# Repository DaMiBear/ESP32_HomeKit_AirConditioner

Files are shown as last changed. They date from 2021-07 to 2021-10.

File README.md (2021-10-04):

# 接入HomeKit的ESP32空调控制器
## 更新日志

- **2021.9.25**：根据power_save例程添加了light-sleep模式及DFS，系统自动决定CPU频率和是否进入light-sleep模式。

  **因为手里只有一个量程为20A的电流表（小量程用不了），测得结果肯定不准确，之前的代码在不用家庭App操控时的电流大约为30\~40mA，现在大约为10\~20mA，如果与家庭App通信时电流大约为40~70mA**

  目前只添加了WiFi使用HARDCODED时的代码；以及`rmt_config_t`变量中的成员`flags`设置为`RMT_CHANNEL_FLAGS_AWARE_DFS`和`clk_div`为`1`以支持DFS；在发生红外指令时，调用电源管理锁`esp_pm_lock_handle_t`防止自动进入light-sleep模式。

  1. 需要在menuconfig中启动`Support for power management`和`Tickless idle support`选项，以及进行`WiFi listen interval`、`power save mode`和`Maximum/Minimum CPU frequency`配置

  2. 需要在`esp-homekit-sdk/examples/common/app_wifi/app_wifi.c`中275行
  
  ```c
  #ifdef CONFIG_APP_WIFI_USE_HARDCODED
  #define APP_WIFI_SSID   CONFIG_APP_WIFI_SSID
  #define APP_WIFI_PASS   CONFIG_APP_WIFI_PASSWORD
  ```

  下面添加如下宏定义：
  
  ```c
  #define DEFAULT_LISTEN_INTERVAL CONFIG_APP_WIFI_LISTEN_INTERVAL
  
  #if CONFIG_APP_POWER_SAVE_MIN_MODEM
  #define DEFAULT_PS_MODE WIFI_PS_MIN_MODEM
  #elif CONFIG_APP_POWER_SAVE_MAX_MODEM
  #define DEFAULT_PS_MODE WIFI_PS_MAX_MODEM
  #elif CONFIG_APP_POWER_SAVE_NONE
  #define DEFAULT_PS_MODE WIFI_PS_NONE
  #else
  #define DEFAULT_PS_MODE WIFI_PS_NONE
  #endif /*CONFIG_POWER_SAVE_MODEM*/
  ```

  3. `app_wifi_start()`函数中`password`下面添加一行

  `.listen_interval = DEFAULT_LISTEN_INTERVAL,`

  4. `ESP_ERROR_CHECK(esp_wifi_start() );`下面添加
  
  ```c
  ESP_LOGI(TAG, "esp_wifi_set_ps().");
  esp_wifi_set_ps(DEFAULT_PS_MODE);
  ```
  
  > 相关宏定义会在main/Kconfig.projbuild文件中自动生成。
  >
  > 附上修改后的[app_wifi.c](/docs/changed_src/app_wifi.c)文件。

## 介绍

- 因为宿舍空调遥控器有问题，而且最近没啥事情做，所以想到使用ESP32做一个空调伴侣，接入Apple的HomeKit实现iOS设备对空调的控制，目前只能对美的空调进行控制，只包括基本功能：**开关**、**模式**(自动、制冷、制热)、**温度**(制冷17-30℃，制热17-25℃)、**风速**(自动风、低、中、高风)。锂电池供电，可用MicroUSB接口充电，充满自动断开，基本的锂电池保护（硬件是设计了但我也没实际测试过O(∩_∩)O），锂电池保护，DW07D这里要注意一点，就是如果第一次装上电池，需要先充电一下才能正常供电，只要不把电池拆下来，就不必再这样做。

- 目前问题或bug(具体原因[笔记](/Note.md)中会解释)：
	- 家庭App界面，在设定空调一些参数后（比如模式），长按配件后出现的设定界面会更新状态，但是打开家庭的初始界面中不能立刻更新，必须把家庭App切到后台再切回来才能更新。
	- 家庭App中空调制热的设定范围，注意是显示的设定范围，是到0\~25℃，制冷温度的设定范围是10\~35℃，实际上如果超出了17\~30℃这个范围的话就还是17℃或者30℃。

- 这个项目参考了乐鑫的homekitSDK和ESP-IDF中的红外NEC编码示例。以及美的的R05D编码的文档。相关链接放在下面：

>  [ESP HomeKit SDK](https://github.com/espressif/esp-homekit-sdk) 其中的/examples/emulator例程相当于是一个仿真，在这个例程里可以创建很多的homekit支持的配件，但是没有实际的效果，参考了里面air conditioner的一段程序。这个SDK都是没有MFI认证的Non-Commercial-Version，所以配对时都会提示此配件不可信任，具体关于homekit协议的参考[HAP-Specification-Non-Commercial-Version](/docs/pdf/HAP-Specification-Non-Commercial-Version.pdf)这个文档。
>  
> [ESP-IDF NEC](https://github.com/espressif/esp-idf/tree/master/examples/peripherals/rmt/ir_protocols) 乐鑫官方的SDK ESP-IDF中的关于NEC编码的例程。
> 
> [R05D介绍](https://www.codenong.com/cs109263771/) 介绍了关于美的空调的红外编码R05D格式，以及一些红外遥控的代码，其中最重要的就是高位先发，低位后发，而且发的是和定义的码电平相反的，这个其他很多文档我都没看到说。以及[ir_Coolix.h](https://github.com/crankyoldgit/IRremoteESP8266/blob/master/src/ir_Coolix.h) 这个红外库的头文件中也可以部分参考(我能发现的就是模式那里这个ir_Coolix.h中多了一位)。

- 这个项目，我很多东西也都是才接触，所以难免有不准确不合适或者错误的地方，看到的兄弟麻烦指出来。
- [视频地址](https://www.bilibili.com/video/BV1eU4y137YL/)

## 硬件连接

只用了一个GPIO18，你可以选择IO直接驱动红外二极管，最好加个NPN三极管或者N沟道的MOSFET驱动。一开始测试的时候我是IO18接到红外二极管正极，通过一个220欧的电阻再到GND，我担心把IO搞坏掉，所以电阻阻值比较大，在220欧的情况下，红外发射距离大致只有5m。所以后面打样的PCB中设计的电路如下：

[具体的AD文件](/docs/原理图PCB)

> 如果图片不显示，请科学上网。或者到/docs/images/目录下查看。

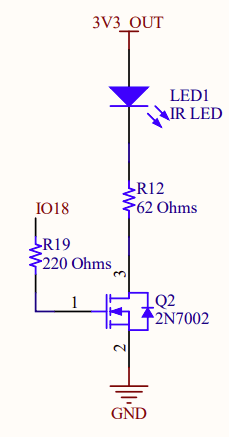
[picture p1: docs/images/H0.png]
H0


## 环境搭建

- ESP-IDF
- ESP HomeKit SDK

### ESP-IDF

要搞好关于ESP-IDF的安装，需要一个比较好的网络，我安装失败了很多次，几乎都是网络问题。具体请参考[官方教程](https://docs.espressif.com/projects/esp-idf/zh_CN/latest/esp32/get-started/index.html)。我只是补充一下，如果用windows的[ESP-IDF 工具安装器](https://dl.espressif.com/dl/esp-idf/?idf=4.4)嫌麻烦建议直接下载离线版本，虽然大，但是解千愁，不会出现什么失败的问题。如果是想用[VS Code的IDE插件](https://github.com/espressif/vscode-esp-idf-extension)的话，也最好找个网好的地方安装，如果本地没有esp-idf，那么要是esp-idf下载失败就会从头开始下载，即使使用本地的esp-idf文件，但是还是需要下载其他东西的，而且这些东西，也挺容易下载失败的，我自己下的时候就算科学上网也是失败了很多次。我下载的时候是4.2版本的，后面更新到4.3也是可以的（4.3好像会弹一些警告），下面以VS Code的IDE插件为例。

### ESP HomeKit SDK

具体也请参考[官方教程](https://github.com/espressif/esp-homekit-sdk)，前提是先安装好ESP-IDF。

## 项目编译、烧录

### 编译准备

1、先把这个项目文件夹放到/esp-homekit-sdk/examples目录下面.

**切记**项目文件夹的路径不要太深，导致路径太长，这样会导致编译过程中出现问题。

> 因为默认[CMakeList.txt](/CMakeLists.txt)的文件是读取上上级目录中的HomeKitSDK的路径，如下面所示。或者修改根目录下的CMakeLists.txt文件里面添加HomeKitSDK的组件也可以，[CMakeLists文件说明传送门](https://docs.espressif.com/projects/esp-idf/zh_CN/latest/esp32/api-guides/build-system.html#cmakelists)。或者自己定义系统变量`HOMEKIT_PATH`

	if(DEFINED ENV{HOMEKIT_PATH})
	  set(HOMEKIT_PATH $ENV{HOMEKIT_PATH})
	else()
	  set(HOMEKIT_PATH ${CMAKE_CURRENT_LIST_DIR}/../..)
	endif(DEFINED ENV{HOMEKIT_PATH})

2、使用VS Code打开这个项目文件夹，先clean一下项目，按F1输入ESP Full Clean Project（如果有build文件夹就是把build文件夹删除）要不然里面的某些文件路径可能会导致编译会报错，除非项目路径和我编译时候的一模一样。



3、F1打开输入ESP Device configuration 选择自己使用的设备。



4、选择端口，同样的F1后输入ESP Select port to use选择使用的端口，要先插上板子才会显示。



5、提前设置好wifi的名称和密码，点击左下角的插件中的齿轮图标，然后点击App Wi-Fi，选择使用	Use Hardcoded，填入wifi名称和密码，保存。


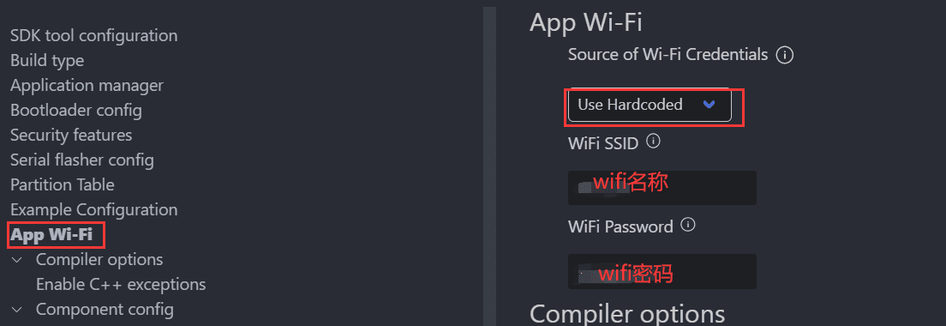
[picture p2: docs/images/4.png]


> 这个如果使用的是ESP-IDF的CMD或者PowerShell的话（就是安装完ESP-IDF，开始菜单里面多的那俩），再进入到项目根目录下敲入`idf.py menuconfig`这个命令，也会出现相同的设置。
> 这个设置完后，我的理解是把设置的信息都保存到了一个[sdkconfig](/sdkconfig)文件里面，**如果上面的wifi名称有中文，那么这个文件里面的`CONFIG_APP_WIFI_SSID`的值实际上是乱码的，需要在sdkconfig文件中找到`CONFIG_APP_WIFI_SSID`这个定义然后改正确**
> 
> 或者在App WiFi中也可以不选择Use HardCode而选择Use Provisioning，这样不需要先准备好wifi名称和密码，而是在烧录完程序后，他会弹出个二维码，需要下载**ESP BLE Prov**这个App去扫描，用蓝牙连接后再设置wifi。

这里还可以改变到时候在家庭App中配对的代码，默认是11122333，也可以在sdkconfig文件中修改。

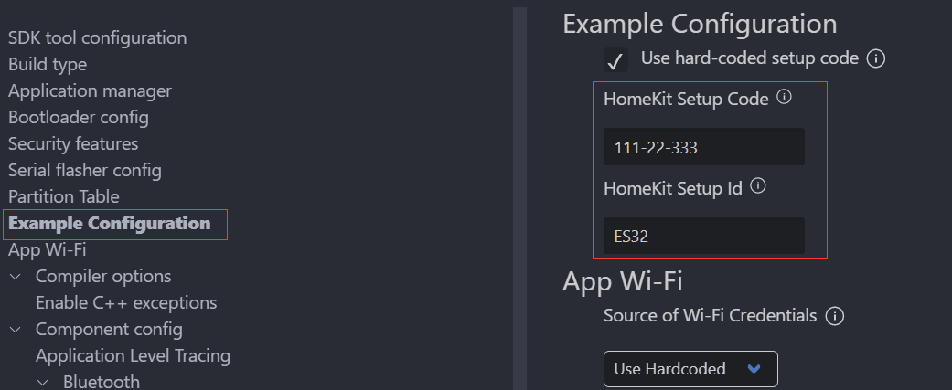
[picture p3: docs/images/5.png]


> 如果上面的过程中遇到什么问题了，先别忘了clean project，然后可以试一试ESP-IDF PowerShell来搞上面的这些，我在使用的时候，有时候就是VS Code插件里面的会报错，但是ESP-IDF PowerShell里就不会。

### 编译、下载、监视 一条龙服务

上面没问题的话，就可以点击左下角的火焰按钮了，或者依次点击左边三个也是一样的。

> 下载的时候，先把GPIO0拉低（按住GPIO0的按钮SW1不放），然后让EN引脚拉低一下（按下EN的按钮SW2松开），看见控制台有提示连接上后就可以松开GPIO0的按钮SW1了。



在监视的输出界面中，他会弹出个二维码，在iOS设备和ESP32在同一个wifi的情况下，使用家庭App扫描这个二维码就可以配对了，这样就不需要输出那个配对码11122333了

如果二维码扫描不了，但是又想扫的话，可以点击二维码下面的链接。

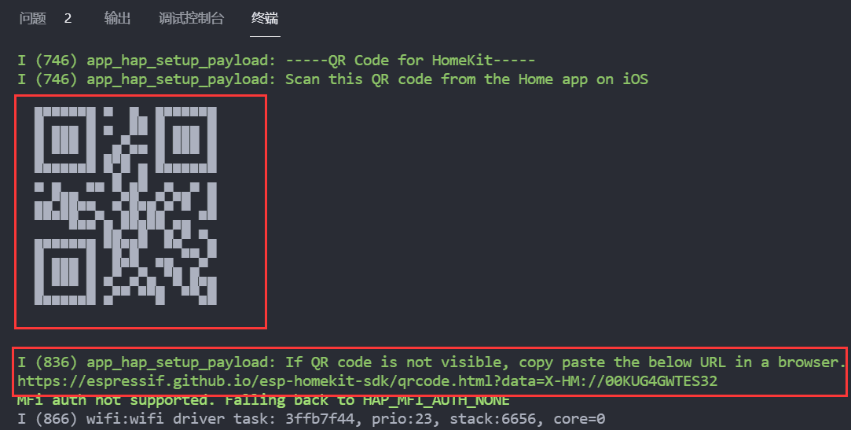
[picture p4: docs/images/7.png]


或者也可以选择“我没有或无法扫描代码”，手动输入配对码添加配件。

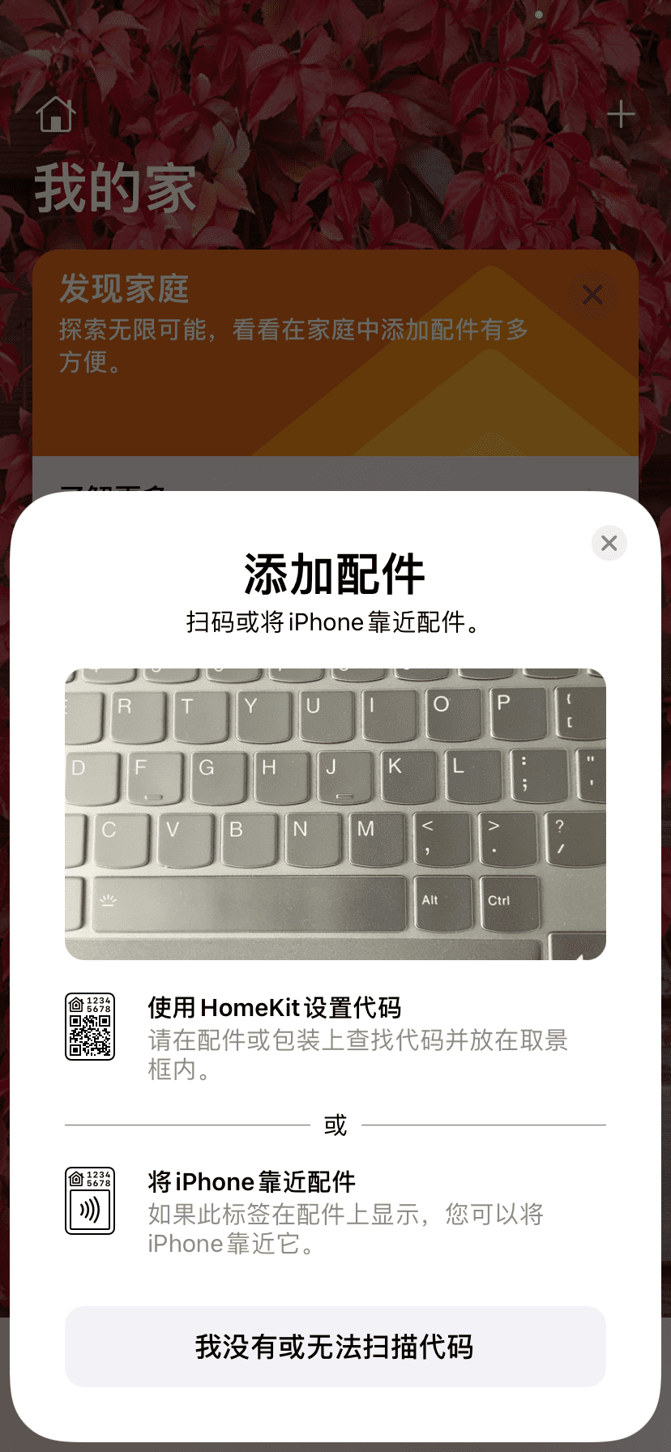
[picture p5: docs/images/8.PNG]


一般没有问题的话，他会直接找到这个配件，就像下面这样，点击后输入11122333就可以配对了。

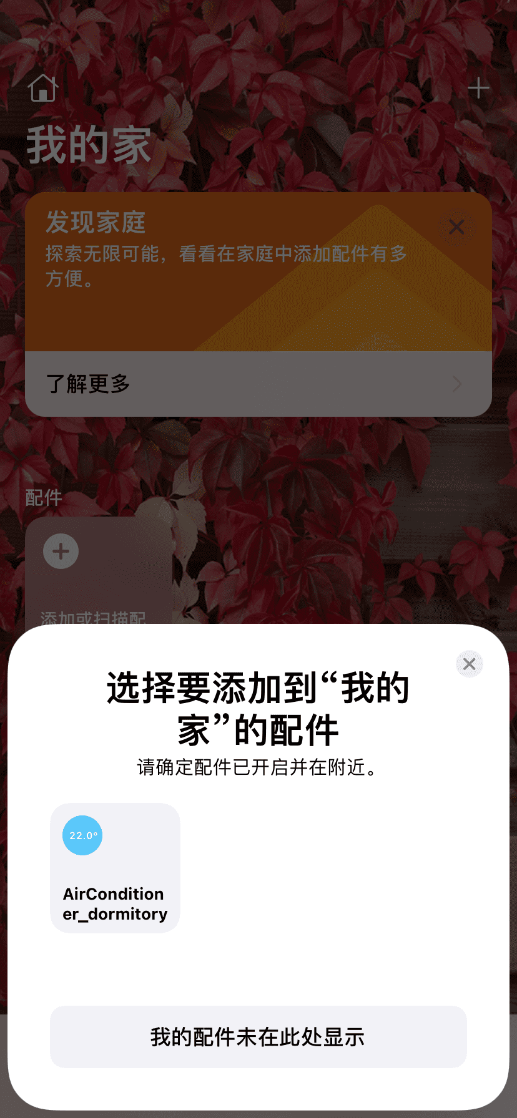
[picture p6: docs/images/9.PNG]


没有MFI认证就会有这个弹窗，点击仍然添加就是啦

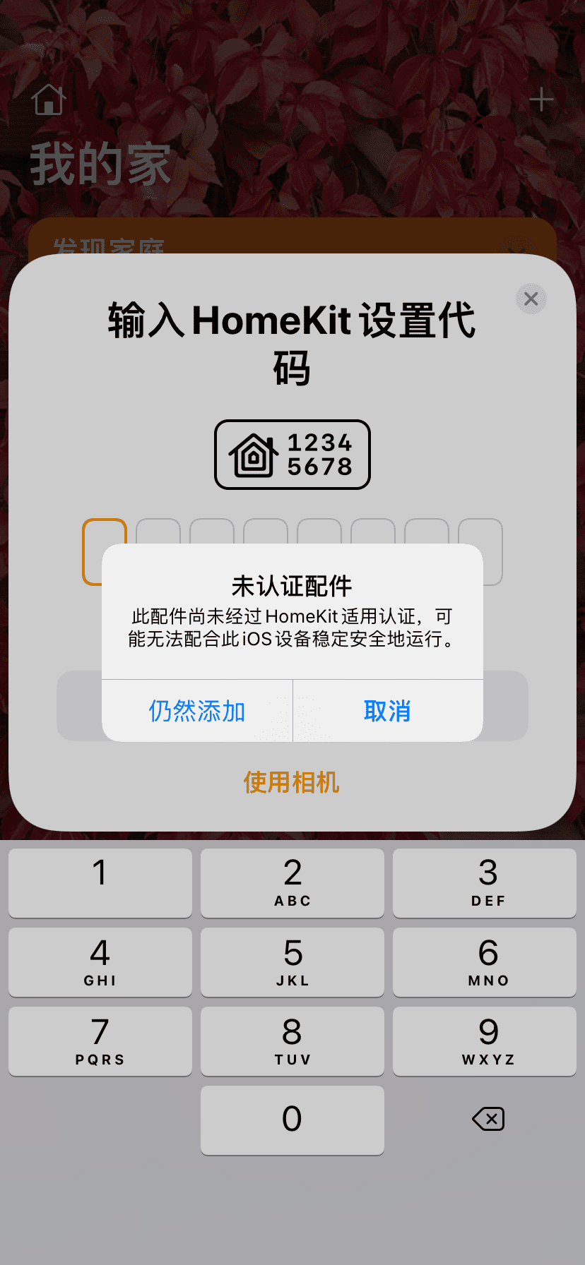
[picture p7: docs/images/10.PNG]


配对完成后，监视控制台应该也可看到相应的输出，按“Ctrl+]”可以退出监视器。

## 使用

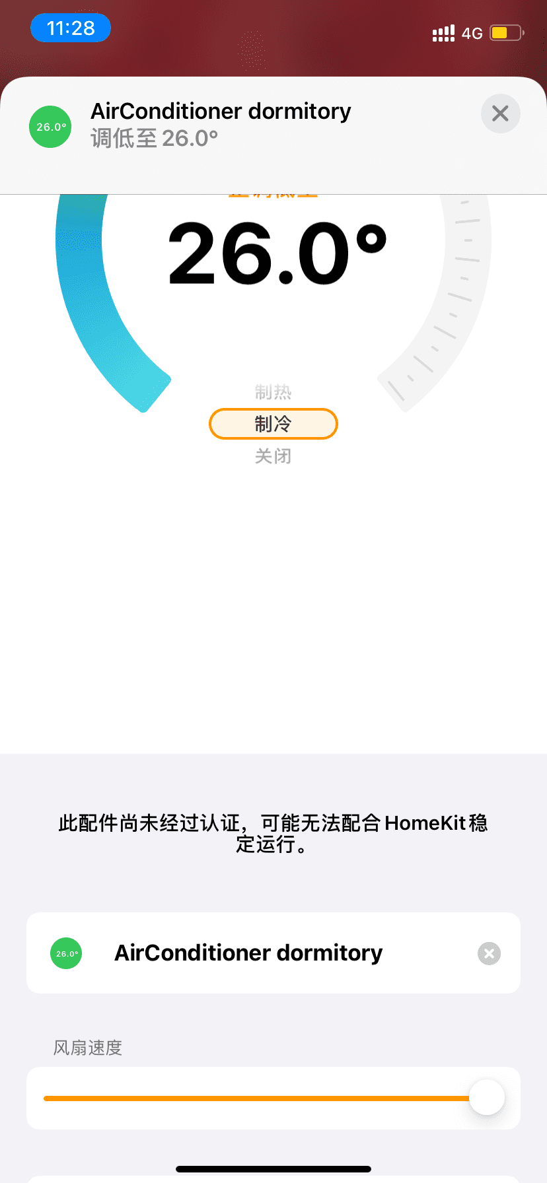
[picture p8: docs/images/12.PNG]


在家庭App刚刚添加的这个空调配件中，自动模式、制冷模式、制热模式、关闭和设置温度都可以使用，只要不是关闭其他模式都会打开空调。

温度虽然可以设定为小数xx.5℃，但是实际上设定的温度会去掉小数部分。关于设定范围，这个问题在开头提了。

下面的风扇速度对应着空调的风速，因为是一个滑块，滑倒最左边相当于关闭空调，0\~33％低风，33\~66％中风，66\~99％高风，100％也就是最右边为自动风。

> 因为这个滑块在滑动的时候会不断的发送新的值给配件，所以在配件程序里设置了一个延时发送的程序，如果在接收到新的指令后的1.5S内，没有新的指令到来了，才发送红外指令，如果有新的指令，那么上一个指令会被覆盖，再等待1.5S，直到没有新的指令到来后才发送。
> 
> 所以存在1.5S+的延时，有种反应速度慢的感觉。

有一个值得提醒的是：你在长按配件打开详情界面时，这时会发送一次红外指令出去，也就是你当时设置的状态。

至于延时关机开机的功能，没有加上去，第一因为懒，第二是因为在快捷指令App中的自动化可以完成这些功能。

具体的细节，硬件设计思路，程序思路可以参考本人的[笔记](/Note.md)。

## 遇到的bug

- 在添加DFS和light-sleep调试的时候，遇到过下载程序后复位发生两次或者数次重启的情况，在断开USB接口重新插入后正常启动，后来这些bug莫名其妙消失了，也许是因为清空了FLASH。

- 在IOS15时，添加配件完成后，对配件进行相关操作时，家庭App中无法切换至显示操作后的状态，比如一开始是关闭状态，要设置为制冷模式，家庭App中设置以后，配件实际上执行了相应的操作，但是在家庭App中还是立马切换至了关闭的状态。这种情况关闭家庭App后重新打开即可。
- IOS15中，改变风速后，遇到过一次配件接收不到相应的指令的情况。也许是因为`power save mode`设置为`minimum modem`的原因。

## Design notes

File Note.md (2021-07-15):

# ESP32 HomeKit AirConditioner项目笔记

我是小白，肯定有一些欠妥的地方，欢迎批评指正！

## 硬件部分

[原理图和PCB文件](/docs/AD_files)可以在/docs/原理图PCB中找到。

### 锂电池充电放电

##### 锂电池充电MCP73833

首先USB5V进来，通过MCP73833锂电池充电芯片给锂电池充电，这个芯片是参考[peng-zhihui的Gluon-Power](https://github.com/peng-zhihui/Project-Quantum/tree/master/1.Hardware/Gluon-Power)才用的，因为之前没没有设计过锂电池相关的电路。

可以驱动三个LED显示当前充电状态，R6那个1KΩ的电阻确定充电电流为1A，达到4.2V LED会显示充满并停止充电。

##### USB 锂电池供电选择

这个电路是群里大佬分享的，因为担心在插着USB充电的情况下，锂电池边充电边放电会有问题，所以才有这个电路。功能就是在有USB5V接入的时候，DCDC芯片的输入是USB5V提供的，而断开锂电池的输入；在没有USB5V接入时，DCDC芯片的输入是锂电池提供。这样就可以做到充电的时候只是单纯的给锂电池充电，同时5V输入负责给ESP32供电。[原理传送门](https://mp.weixin.qq.com/s/PFX6RQysr8UhUfQNe2Paqg)。

##### 锂电池保护电路DW07

网上随便找的一个芯片DW07，按照数据手册的电路图链接的。具体细节没有研究。

##### DCDC芯片TPS6300

在TI官网找的一个满足功能，价钱合适的一款buck-boost芯片TPS6300。自动切换升压降压模式，这一款是可以根据分压电阻改变输出电压的，主要还是可变电压的这一款便宜点。最大电流可以达到1A（如果我没理解错的话），因为用了7个红外二极管，每个大概50mA，一共就350mA了，再加个ESP32的电流，所以找的这个能输出1A的芯片。

### ESP32模块

这个没什么好说的，我怕天线那部分搞不好，所以直接买的模组。只把下载口，使能，启动模式接口引了出来。但是在送出去打样之后我发现个问题，我在设计PCB的时候，当时还纳闷为什么模组天线下面低层敷铜的话敷不上去，模组不是在顶层吗？后来想到应该是防止电磁屏蔽之类的，但是我PCB除了天线之外的部分底层都敷铜了，这样应该会影响到信号吧。

### 红外二极管驱动

这里选择用N沟道的MOSFET来驱动，为什么不用P沟道，我是这样想的：因为ESP32的rmt模块输出的信号是38kHz调制后的，比如要发送引导码（高4.4ms再低4.4ms），相当于要让红外二极管前4.4ms是有38kHz的脉冲，后面4.4ms是没有导通的，也就是MOSFET前4.4ms以38kHz以占空比33％导通，后面4.4ms关闭，用N沟道的话很好理解，4.4ms的高电平加上4.4ms的低电平经过调制接到MOSFET的G极就好了，但是如果用P沟道，P沟道的G极的电平是要前4.4ms以占空比66％为高电平（其中的33％的低电平P-MOS是导通的），后4.4ms为高电平，调制前的引导码怎么设计才能输出这样的波形呢？我能想到的是，IO口一直输出高电平，但是前4.4ms调制，后4.4ms不调制，这样没有N沟道用着简单。

## 软件部分

就按照程序的启动顺序来写。

### HomeKit

##### 核心概念

首先要知道，在HomeKit中，定义了一个配件accessory，一个配件可以有多个服务service，每个服务又可以有多个特征characteristic。比如一个有照明功能的风扇，这是一个配件，但是他又三个服务：必备的的信息服务the Required Accessory Information service、风扇服务a Fan service、电灯服务a Light Bulb service；在风扇服务中，又有多个特征，必备的特征：状态Active，可选则特征：名称Name，转向Rotation Direction，转速 Rotation Speed等等。这些以及被定义的服务和特征都可以在[HAP-Specification-Non-Commercial-Version.pdf](/docs/pdf/HAP-Specification-Non-Commercial-Version.pdf)找到。特征又包括读写权限，这个就是造成某些信息在改变后不能即使更新，而是必须把App切到后台再切回来才能更新的原因。

在这个项目中，只有一个空调服务，查看代码可以直到，这个所谓的空调，实际上是用的HomeKit中定义的恒温器来实现的。恒温器和空调确实不是一个东西，当时我也看了一些以及做好的空调伴侣中家庭App的显示，也都是以恒温器的界面来显示的。为什么HomeKit不专门定义一个空调服务呢？就是因为是恒温器，才造成了一堆问题。

恒温器目前定义的特征有：
- Active（开关状态）- 读写
- Current Temperature（当前环境温度）- 只读
- Current Heater Cooler State（当前运行模式）- 只读
- Target Heater Cooler State（设定的模式）- 读写
- Name（名称）- 只读
- Rotation Speed（转速）- 读写
- Cooling Threshold Temperature（开始制冷门限）- 读写
- Heating Threshold Temperature（开始制热门限）- 读写

> 这里的读写，是以家庭App为主语来说的，是家庭App的读写权限。但是在ESP32上，这些值不论读写，都是可以被改变的。

在家庭App的配件的详情页中，三种模式（自动、制热、制冷）对应的是Target Heater Cooler State，制冷制热模式对应的温度是Cooling Threshold Temperature或者Heating Threshold Temperature，转速对应Rotation Speed，开关对应Active。

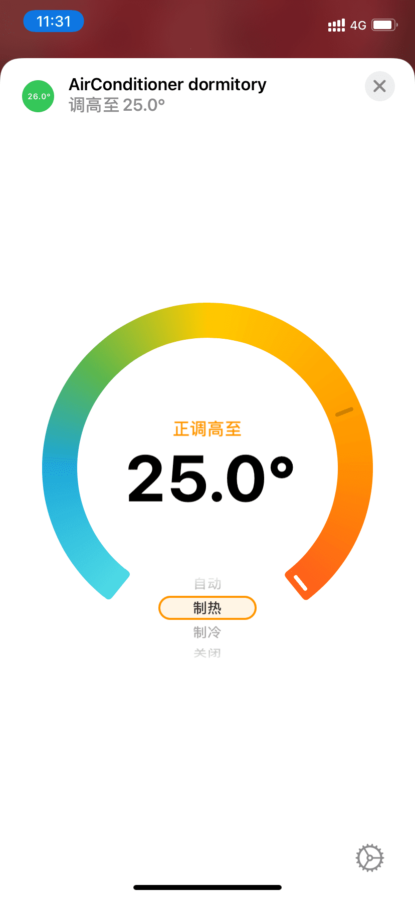
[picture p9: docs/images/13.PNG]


##### 温度范围问题：

发现没有，这些特征都是可写的。同时这也是为什么在制热模式下，最高温度只能开到25℃的原因，因为这个25℃是在Heating Threshold Temperature特征中被HoneKit限制死的，实际上设定的是制热门限，就是说，温度到了XX度以下开始制热的温度，所以HomeKit最高才给了25℃，同样的Cooling Threshold Temperature最高能到35℃，意思是说超过35℃之后开始制冷的温度。什么叫TM的惊喜！这就叫TM的惊喜！

##### 只读特征刷新问题：

而在刚刚打开家庭App的界面上，“我的家”三个字下面的圆环里的温度对应着Current Temperature，圆环下面的“关闭”的位置对应着Current Heater Cooler State，因为关闭的时候没有模式一说，所以显示的是关闭，这个问题不大。主要是：在详情页中改变了温度和模式之后，再回到刚开始的页面（前提是不切到后台再进来），会发现圆环里的温度还是原来的温度26℃，模式显示的是“闲置”，这个26和闲置，是刚刚创建恒温器服务时赋的初值。所以说刚刚修改的模式和温度并没有在这里体现，因为他们根本不是一个特征啊！**这些特征是只读的，目前只发现在打开或者从后台切出家庭App时这些特征会被重新读取，没有找到主动读取的方法。**

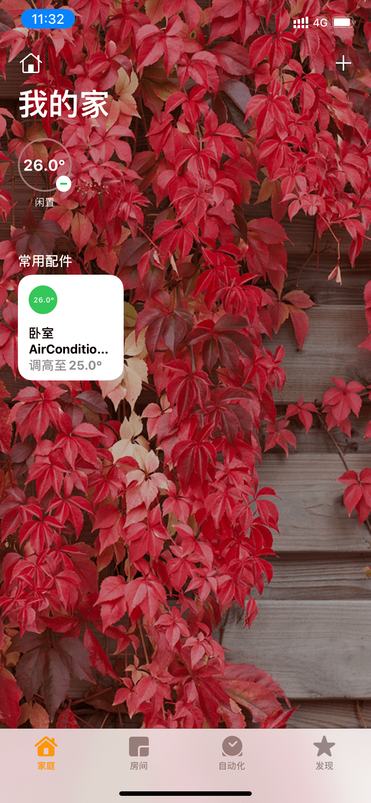
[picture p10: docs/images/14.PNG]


### ESP HomeKit SDK

##### Register Service Write/Read callback

程序在创建完上面配件必要的一些服务和特征时候，就会添加写回调函数`hap_serv_set_write_cb(service, air_conditioner_write)`和读回调函数`hap_serv_set_read_cb(service, air_conditioner_read)`了。我目前的理解只是知道在家庭App中写入特征的值时会调用`air_conditioner_write`在读取时会调用`air_conditioner_read`同时这两个函数的返回值，如果返回失败，那么家庭App中就会显示配件“未响应”

- `air_conditioner_write`：它一次处理的是多个特征的值，比如从关机状态切换到制冷状态，会发送Target Heater Cooler State和Active这两个特征的值（因为温度默认初始26℃，所以没有发送）所以函数的参数是一个`hap_write_data_t`的数组，for循环每次只对其中一个特征进行匹配和处理，记录下设定的值用来发送红外指令和`air_conditioner_read`中的更新。然后把这些新的值通过`hap_char_update_val`写入到HAP Core中完成更新。

	> 这里一开始有一个小bug，就是在改变模式的时候，不知道为什么，家庭App会向配件发送两次相同的数据，就是会调用`air_conditioner_write`两次（如果你用Siri会发送三次，第一次是原来的模式，后面两次是修改后的模式），在监视器输出中也能看到打印的信息有两次是重复的。不过不处理的话，ESP32会连续向空调发送重复的红外指令，所以后面添加了一个1.5S的等待新指令的程序来解决这个。
	> 
	> 还有一个值得注意的是：我猜测，HAP Core中有这些特征真正的值，`air_conditioner_write`参数中的都只是拷贝罢了，因为最后是要调用`hap_char_update_val`才是真正的写入。

- `air_conditioner_read`：这个不同于`air_conditioner_write`会一次输入多个特征的值，而是一个特征对应一次调用。为了改变上面的只读特征刷新的问题，在上面的`air_conditioner_write`处理对应特征的时候记录了设定的温度和模式，这样最起码能在下次打开App时刷新，而不是圆圈里一直显示着26℃和“闲置”，比如，在改变制冷模式下的温度时，设定的实际上是Cooling Threshold Temperature，处理这个特征的时候保存了当前设定的温度，再后面重新切回到家庭App时，`air_conditioner_read`会被调用，此时就根据之前记录的设定的温度和设定的模式更新Current Temperature为设定的温度，Current Heater Cooler State为设定的模式，以及Cooling Threshold Temperature和Heating Threshold Temperature为去掉小数后的值。然后调用`hap_char_update_val`写入到HAP Core中完成更新。其他可以读取的特征在这个函数里都要进行处理，目的是要返回`HAP_SUCCESS`不让配件显示为未响应的情况。

	> `hap_char_update_val`是把特征的值写入到HAP Core中，所以说**每次打开家庭App中读取的状态或者值是从HAP Core中读取的**。
	> 
	> 一开始是没有`hap_serv_set_read_cb(service, air_conditioner_read)`这行代码登记回调函数的，这种情况下只会去读取`air_conditioner_write`中被更新的值。

**所以说目前最大的问题就没有找到让家庭App主动去读HAP Core中特征的值的办法，这样就不需要折腾了。**

### RMT (Remote Control) module driver

##### 基本介绍

这个是ESP-IDF自带的一个发送和接收红外遥控信号的库，可以设定载波的频率和占空比，然后自动帮你把要发送的码元进行调制。这个项目代码是基于NEC例程的代码改过来的。有两个名词需要知道，具体的[官方文档](https://docs.espressif.com/projects/esp-idf/zh_CN/latest/esp32/api-reference/peripherals/rmt.html)有详细介绍。
- items：一个长度为32bit的结构体，bit0-bit14是电平1持续的周期（单位ticks），bit15是这个电平1的高低；bit16-bit30是电平2持续的周期，bit31是电平2的高低。对应的结构体类型是`rmt_item32_t`，如果items中的周期为0，则会停止发送。
- ticks：是时钟分频后的方波周期，项目里是80M的80分频，也就是1us。

在发送摩斯电码的例程中，启动发射的函数`rmt_write_items(ac_tx_channel, items, length, true)`就是按照rmt_item32_t数组中的信息来发送的。

要搞清楚三个结构体类型（源码也贴在下面了）：

- `ir_builder_config_t` ：ir_builder的配置

		typedef struct {
			uint32_t buffer_size; /*!< Size of the internal buffer used by IR builder */
			ir_dev_t dev_hdl;     /*!< IR device handle */
			uint32_t flags;       /*!< Flags for IR builder, different flags will enable different features */
		} ir_builder_config_t;

- `nec_builder_t` ：NEC编码的一些引导码等码的高低电平时间，自己添加了分割码，以及rmt_item32_t数据存放的空间的首地址

		typedef struct {
		    ir_builder_t parent;
		    uint32_t buffer_size;
		    uint32_t cursor;	// 记录当前读取到的items的下标
		    uint32_t flags;
		    uint32_t leading_code_high_ticks;
		    uint32_t leading_code_low_ticks;
		    uint32_t repeat_code_high_ticks;
		    uint32_t repeat_code_low_ticks;
		    uint32_t payload_logic0_high_ticks;
		    uint32_t payload_logic0_low_ticks;
		    uint32_t payload_logic1_high_ticks;
		    uint32_t payload_logic1_low_ticks;
		    uint32_t ending_code_high_ticks;
		    uint32_t ending_code_low_ticks;
		    uint32_t divide_code_high_ticks;    // 添加分割码
		    uint32_t divide_code_low_ticks;
		    bool inverse;
		    rmt_item32_t buffer[0];
		} nec_builder_t;

- `ir_builder_t` ：在`nec_builder_t`中使用的一个变量类型，主要是存放一些回调函数的地址，也添加了分割码

		struct ir_builder_s {
		    uint32_t repeat_period_ms;
		    esp_err_t (*make_head)(ir_builder_t *builder);
		    esp_err_t (*make_logic0)(ir_builder_t *builder);
		    esp_err_t (*make_logic1)(ir_builder_t *builder);
		    esp_err_t (*make_end)(ir_builder_t *builder);
		    esp_err_t (*build_frame)(ir_builder_t *builder, const AC_R05D_PAYLOAD_CODE send_code);
		    esp_err_t (*build_repeat_frame)(ir_builder_t *builder);
		    esp_err_t (*build_divide_frame)(ir_builder_t *builder);
		    esp_err_t (*get_result)(ir_builder_t *builder, void *result, uint32_t *length);
		    esp_err_t (*del)(ir_builder_t *builder);
		};

##### 大致流程

###### 配置

先根据基本的配置信息进行配置，`ir_builder_config_t`类型的变量`ir_builder_config`设置的保存items的空间大小为128个items（`nec_builder_t`中的`buffer`就是指向的这额外128*32bits的空间的首地址）。然后调用`ir_builder_rmt_new_nec`返回给一个`ir_builder_t`类型的`ir_builder`变量，这个函数的作用就是开辟了`ir_builder_t`类型大小+额外128个`rmt_item32_t`大小的空间，把首地址给一个`nec_builder_t`类型的`nec_builder`变量，然后根据一些R05D编码时长的宏定义赋值到`nec_builder`变量的成员中保存，以及构造逻辑0逻辑1和引导码，分割码的这些函数指针赋值给`nec_builder`的成员`parnet`的函数指针成员。最后返回`&nec_builder->parent`赋给`ir_builder`。

> 这个时候返回的`ir_builder`变量的成员里主要是一些函数指针，具体的码的时间长度是在他的“父结构体”中的，这也是为什么像`nec_builder_make_head`这些函数中使用了`__containerof(builder, nec_builder_t, parent)`来获取“父结构体”的地址。（这只是我的简单理解）

###### 建立帧结构

基本的准备完成了之后，再根据之前再HomeKit的写回调函数中保存的一些模式温度的信息，就到了发送红外指令的阶段了，先调用之前`ir_builder_rmt_new_nec`返回的`ir_builder`变量传进来的函数地址指向的函数体`nec_build_frame`，顾名思义，就是根据之前的信息建立NEC码（实际上是R05D码）的items，往之前开辟的128个items里放入合适的周期数和电平等级。

先用`__containerof(builder, nec_builder_t, parent)`获得他的“父结构体”的首地址给`nec_builder`变量，因为这个`nec_builder`中存放着一些要发送的码的时长等信息，同时把cursor清零，表示我们从第一个itmes开始填数据。先建立要发送的引导码，就是4.4ms的高电平，再4.4ms的低电平。就是往第一个itmes空间放入电平1的周期为4400个ticks（每个ticks是1us，一共就是4.4ms），电平1的高低为高电平，因为`nec_builder->inverse`的值为`false`，电平2的周期为4400个ticks，电平2的高低为低电平，然后`cursor += 1`这样引导码就建立好了。

> 只能说根据实际来看，很多文档中说的引导码应该是先低电平再高电平，但是**发的时候确是按相反的来发**的，后面的逻辑0逻辑1，分割码，结束码也是一样。就是说发引导码的时候红外二极管要先以4.4ms f = 38kHz D=33％导通，再4.4ms关闭，这里说的和硬件没关系，用P沟道红外二极管也是这样。

后面就是根据R05D的**AA' BB' CC' S AA' BB' CC'** 这样的格式建立起来的，[R05d电控功能说明书](/docs/word/R05d电控功能说明书.doc)，A一般都是固定的0xB2即0b1011 0010，就for循环8次，每次判断是填逻辑0的编码还是填逻辑1的编码，**但是这里是从最高位开始发的要注意！**

咱一开始是不知道要发结束码的，后来怎么搞空调都没反应，走头无路了，就试着加上一个结束码0.54ms的高电平再30ms的低电平，低电平应该够长就行，加上后空调终于有响应了，添加结束码的时候，要把下一个items的周期填0，这样才能停止发送。然后`ir_builder->get_result`这个函数就是把刚刚那块itmes的首地址赋值给传入的指针和长度（长度也就是`cursor`最后的值），这里面的强制类型转换放在等号左边我想了很久。。。之后就是把刚刚填入的那些items的信息通过`rmt_write_items`发送出去就行了。

###### 发送

构造帧，发送帧这些都放在了一个`ac_send_r05d_code(AC_INFO ac_info)`函数中了，根据要发送的空调的信息把AA' BB' CC' S AA' BB' CC'这些赋值不同的代码，再构造帧后发送。原本这个`ac_send_r05d_code`函数在HomeKit的写回调函数的最后会被调用，但因为短时间内发送多条红外指令的问题，改成了把允许发送的`ac_send_r05d_code_flag`变量置为`true`，并且记录HomeKit写回调函数被调用时的tick计数给`ac_send_tick_count`变量，用来给后面的另一个线程判断1.5S内没有新的指令。

###### 发送等待

上面提到的在改变模式时，以及改变风速时，会造成短时间内发送多条红外指令，为了避免这样的问题，新开辟了一个线程，而且FreeRTOS以前没有接触过，就按照其他的一些例程照葫芦画瓢了。

这个线程就是每隔0.1S检查`ac_send_r05d_code_flag`是否为`true`，当为`true`后，检查`ac_send_r05d_code`和`nowTickCount`的差值，如果他们之间的差值大于1.5S的tick个数，那么就根据当前保存的模式发送红外指令，同时把`ac_send_r05d_code_flag`置为`false`否则我们就不发送红外指令。这样如果1.5S内有新的指令到来，`ac_send_r05d_code_flag`就会被更新，那么之前的指令有可能就会被覆盖而没有发送出去，直到1.5S没有新的指令到来，才根据当前的信息发送指令。

这样就发完了一个基本功能的红外指令，其他的重复码，以及空调的高级功能，emmmmmm随缘吧(～￣▽￣)～

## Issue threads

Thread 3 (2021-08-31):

IO输出波形逻辑1似乎由38.46k的脉冲构成

Raiiwhen, 2021-08-31:
如果将脉冲序列定义为逻辑1，可以符合美的空调红外协议，但美的空调协议应该是由高电平构成逻辑1。
另外，似乎up的逻辑1与协议是恰好相反的。
请问是我理解有问题嘛？
附逻辑分析仪所抓到图形：
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

DaMiBear, 2021-08-31:
确实是和网上定义的相反，我的[note](https://github.com/DaMiBear/ESP32_HomeKit_AirConditioner/blob/master/Note.md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) 里也有写。当时这个问题浪费了我很多时间。我当时的参考博客也提到了这点[R05D介绍](https://www.codenong.com/cs109263771/)。

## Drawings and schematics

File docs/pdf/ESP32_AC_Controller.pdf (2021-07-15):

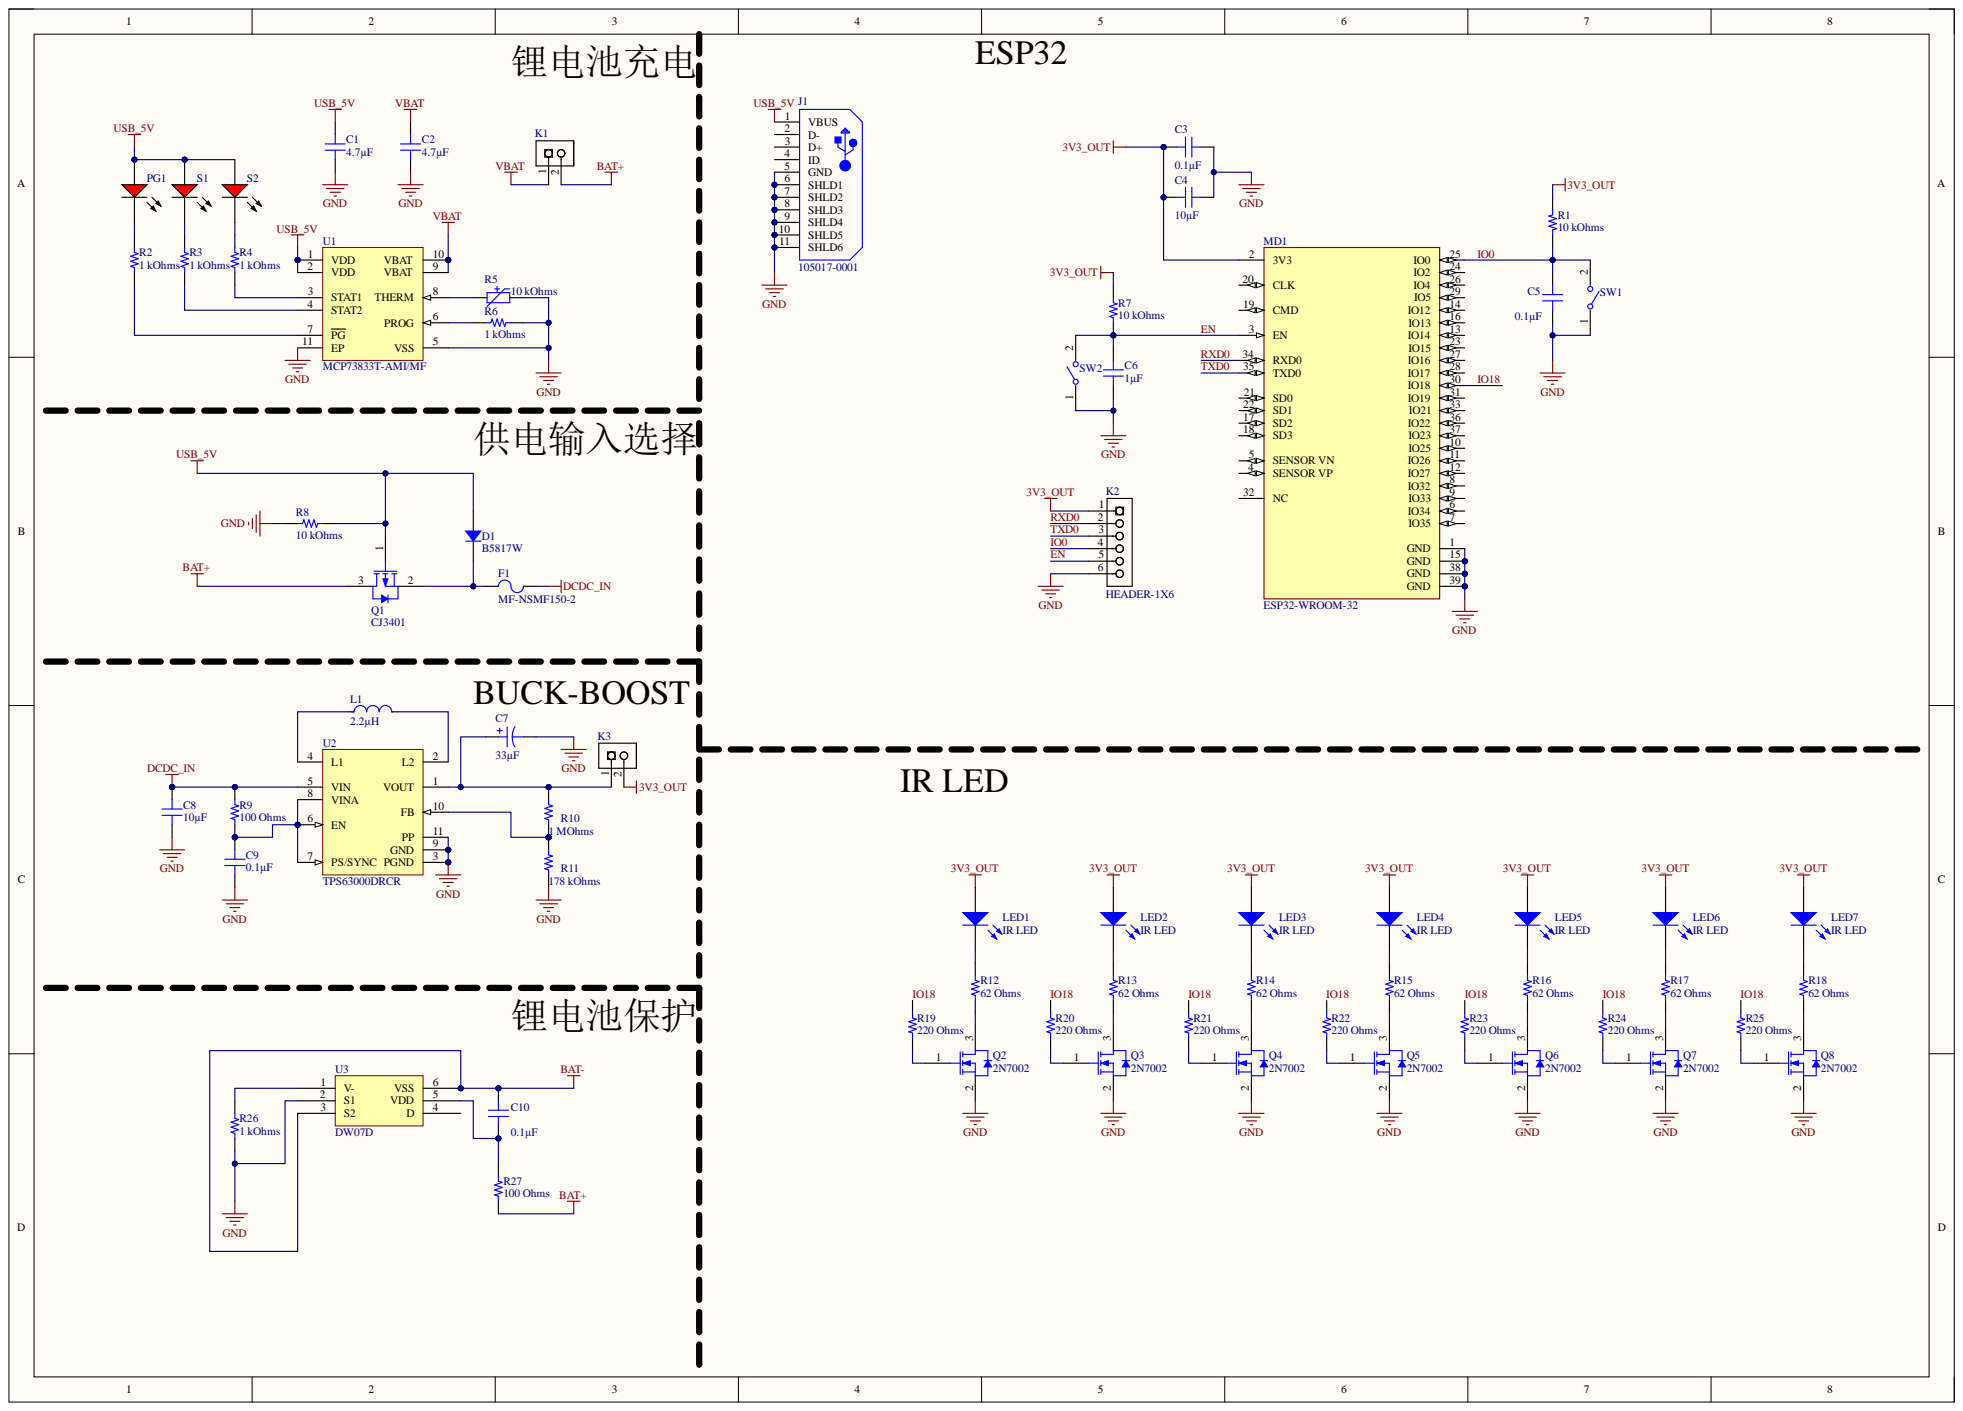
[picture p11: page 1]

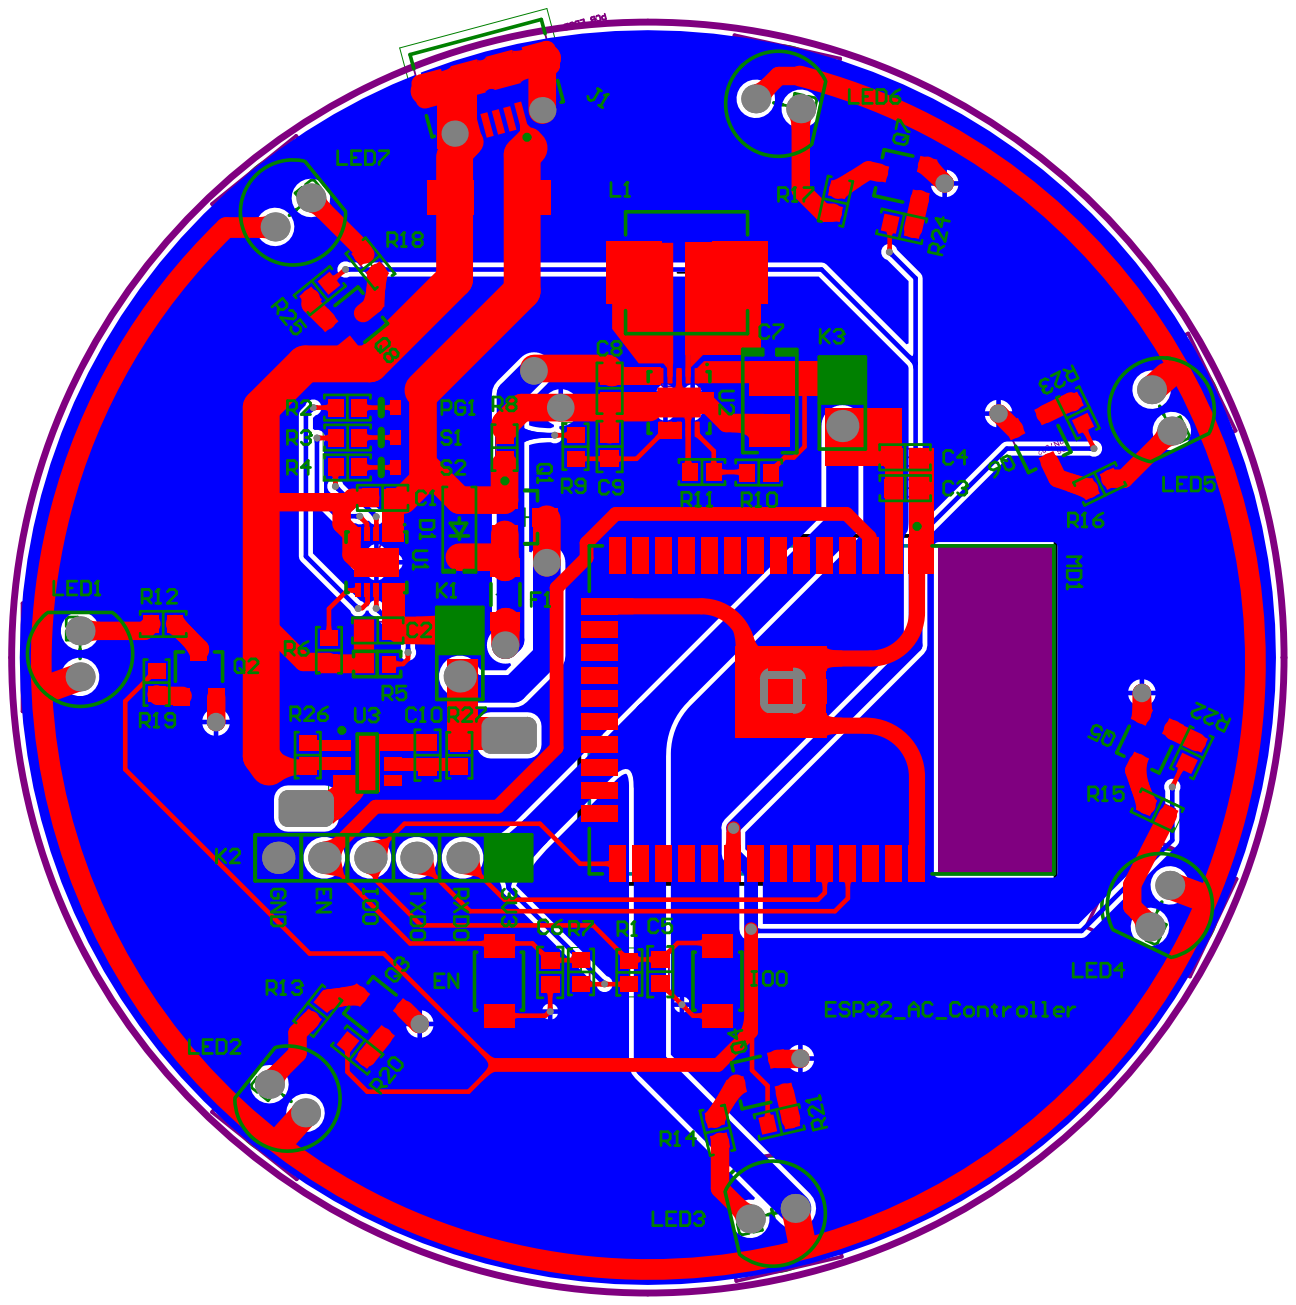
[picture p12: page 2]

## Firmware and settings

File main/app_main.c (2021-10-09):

/*
 * ESPRESSIF MIT License
 *
 * Copyright (c) 2018 <ESPRESSIF SYSTEMS (SHANGHAI) PTE LTD>
 *
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
 */



#include <stdio.h>
#include <string.h>
#include <freertos/FreeRTOS.h>
#include <freertos/task.h>
#include "esp_log.h"

#include <hap.h>
#include <hap_apple_servs.h>
#include <hap_apple_chars.h>
#include <hap_fw_upgrade.h>

#include <iot_button.h>

#include <app_wifi.h>
#include <app_hap_setup_payload.h>

#include "esp_pm.h"
#include "air_conditioner.h"

/* Comment out the below line to disable Firmware Upgrades */
#define CONFIG_FIRMWARE_SERVICE

static const char *TAG = "HAP Air Conditioner";

#define AIRCONDITIONER_TASK_PRIORITY  1
#define AIRCONDITIONER_TASK_STACKSIZE 4 * 1024
#define AIRCONDITIONER_TASK_NAME      "hap_airconditioner"

/* Reset network credentials if button is pressed for more than 3 seconds and then released */
#define RESET_NETWORK_BUTTON_TIMEOUT        3

/* Reset to factory if button is pressed and held for more than 10 seconds */
#define RESET_TO_FACTORY_BUTTON_TIMEOUT     10

/* The button "Boot" will be used as the Reset button for the example */
#define RESET_GPIO  GPIO_NUM_0

static void air_conditioner_send_task(void *arg);

TaskHandle_t air_conditioner_send_task_handle = NULL;

AC_INFO ac_current_info = {
    .on = false,
    .mode = AUTO_MODE,
    .temp = 26,
    .fan_speed = AUTO_FAN_SPEED
};

static TickType_t ac_send_tick_count = 0;

bool ac_send_r05d_code_flag = false;    // 是否可以发送红外信号

esp_pm_lock_handle_t rmt_send_task_pm_lock = NULL;  // 电源管理锁，用于防止在要使用rmt时自动进入light-sleep状态

/**
 * @brief The network reset button callback handler.
 * Useful for testing the Wi-Fi re-configuration feature of WAC2
 */
static void reset_network_handler(void* arg)
{
    hap_reset_network();
}
/**
 * @brief The factory reset button callback handler.
 */
static void reset_to_factory_handler(void* arg)
{
    hap_reset_to_factory();
}

/**
 * The Reset button  GPIO initialisation function.
 * Same button will be used for resetting Wi-Fi network as well as for reset to factory based on
 * the time for which the button is pressed.
 */
static void reset_key_init(uint32_t key_gpio_pin)
{
    button_handle_t handle = iot_button_create(key_gpio_pin, BUTTON_ACTIVE_LOW);
    iot_button_add_on_release_cb(handle, RESET_NETWORK_BUTTON_TIMEOUT, reset_network_handler, NULL);
    iot_button_add_on_press_cb(handle, RESET_TO_FACTORY_BUTTON_TIMEOUT, reset_to_factory_handler, NULL);
}

/* Mandatory identify routine for the accessory.
 * In a real accessory, something like LED blink should be implemented
 * got visual identification
 */
static int air_conditioner_identify(hap_acc_t *ha)
{
    ESP_LOGI(TAG, "Accessory identified");
    return HAP_SUCCESS;
}


static char val[260];
static char * emulator_print_value(hap_char_t *hc, const hap_val_t *cval)
{
    uint16_t perm = hap_char_get_perm(hc);
    if (perm & HAP_CHAR_PERM_PR) {
        hap_char_format_t format = hap_char_get_format(hc);
	    switch (format) {
		    case HAP_CHAR_FORMAT_BOOL : {
                snprintf(val, sizeof(val), "%s", cval->b ? "true":"false");
    			break;
		    }
		    case HAP_CHAR_FORMAT_UINT8:
		    case HAP_CHAR_FORMAT_UINT16:
		    case HAP_CHAR_FORMAT_UINT32:
		    case HAP_CHAR_FORMAT_INT:
                snprintf(val, sizeof(val), "%d", cval->i);
                break;
    		case HAP_CHAR_FORMAT_FLOAT :
                snprintf(val, sizeof(val), "%f", cval->f);
		    	break;
    		case HAP_CHAR_FORMAT_STRING :
                if (cval->s) {
                    snprintf(val, sizeof(val), "%s", cval->s);
                } else {
                    snprintf(val, sizeof(val), "null");
                }
			    break;
            default :
                snprintf(val, sizeof(val), "unsupported");
		}
    } else {
        snprintf(val, sizeof(val), "null");
    }
    return val;
}

/* Callback for handling writes on the Air Conditioner Service
 */
static int air_conditioner_write(hap_write_data_t write_data[], int count,
        void *serv_priv, void *write_priv)
{
    int i, ret = HAP_SUCCESS;
    // static float last_fan_speed = 100;
    // static AC_FAN_SPEED last_fan_mode = AUTO_FAN_SPEED;
    // bool enable_send = false;
    hap_write_data_t *write;
    // printf("DEBUG!!!!!!!!!!! count: %d\n", count);
    for (i = 0; i < count; i++) {
        /* 每次只对一个特征hc进行处理 */
        write = &write_data[i];
        /* Setting a default error value */
        *(write->status) = HAP_STATUS_VAL_INVALID;
        // int iid = hap_char_get_iid(write->hc);
        // int aid = hap_acc_get_aid(hap_serv_get_parent(hap_char_get_parent(write->hc)));
        // printf("Write aid = %d, iid = %d, val = %s\n", aid, iid, emulator_print_value(write->hc, &(write->val)));
        // printf("hap_char_get_type_uuid(write->hc) : %s\n", hap_char_get_type_uuid(write->hc));
        /* 开关操作 */
        if (!strcmp(hap_char_get_type_uuid(write->hc), HAP_CHAR_UUID_ACTIVE)) { // ACTIVE实际上是8位的，但是目前HomitKit中只定义了0和1
            ESP_LOGI(TAG, "Received Write for ACTIVE: %s", write->val.u ? "On" : "Off");
            if (write->val.u == 0)
                ac_current_info.on = false;
            else
                ac_current_info.on = true;  

            *(write->status) = HAP_STATUS_SUCCESS;
            
        } 
        /* 模式操作 */
        else if (!strcmp(hap_char_get_type_uuid(write->hc), HAP_CHAR_UUID_TARGET_HEATER_COOLER_STATE)) 
        {
            if (write->val.u == 0)
            {   // 自动模式
                ac_current_info.mode = AUTO_MODE;
                ESP_LOGI(TAG, "Received Write for TARGET_HEATER_COOLER_STATE: Heat or Cool");
            }
            else if (write->val.u == 1)
            {   // 加热模式
                ac_current_info.mode = HEAT_MODE;
                ESP_LOGI(TAG, "Received Write for TARGET_HEATER_COOLER_STATE: Heat");
            }
            else if (write->val.u == 2)
            {   // 制冷模式
                ac_current_info.mode = COOL_MODE;
                ESP_LOGI(TAG, "Received Write for TARGET_HEATER_COOLER_STATE: Cool");
            }
        
            *(write->status) = HAP_STATUS_SUCCESS;
        } 
        /* 设定制冷温度操作 */
        else if (!strcmp(hap_char_get_type_uuid(write->hc), HAP_CHAR_UUID_COOLING_THRESHOLD_TEMPERATURE))
        {   /* 根据空调实际温度范围进行限制 */
            if (write->val.f > 30 )
            {
                write->val.f = 30;
            }
            else if (write->val.f < 17)
            {
                write->val.f = 17;
            }
            ac_current_info.temp = (uint8_t)write->val.f;
            ESP_LOGI(TAG, "Received Write for COOLING_THRESHOLD_TEMPERATURE: %d", ac_current_info.temp);
            *(write->status) = HAP_STATUS_SUCCESS;
        }
        /* 设定制热温度操作 */
        else if (!strcmp(hap_char_get_type_uuid(write->hc), HAP_CHAR_UUID_HEATING_THRESHOLD_TEMPERATURE))
        {   /* 根据空调实际温度范围进行限制 */
            if (write->val.f < 17)
            {
                write->val.f = 17;
            }
            /** 因为制热门限在制冷门限的下面
             * 所以在自动模式，修改上限或下限温度时
             * ac_current_info.temp先为制冷门限，再被重新赋值为制热门限
             * 空调实际设置的温度总是以制热门限来确定
             */
            ac_current_info.temp = (uint8_t)write->val.f;    
            ESP_LOGI(TAG, "Received Write for HEATING_THRESHOLD_TEMPERATURE: %d", ac_current_info.temp);
            *(write->status) = HAP_STATUS_SUCCESS;
        }
        /* 风扇转速（风速）操作 */
        else if (!strcmp(hap_char_get_type_uuid(write->hc), HAP_CHAR_UUID_ROTATION_SPEED))
        {
            if (write->val.f == 100)
            {   // 自动风
                ac_current_info.fan_speed = AUTO_FAN_SPEED;
                ESP_LOGI(TAG, "Received Write for ROTATION_SPEED: Auto");
            }
            else if (write->val.f > 0 && write->val.f <= 33)
            {   // 低风
                ac_current_info.fan_speed = MIN_FAN_SPEED;
                ESP_LOGI(TAG, "Received Write for ROTATION_SPEED: Low");
            }
            else if (write->val.f > 33 && write->val.f <= 66)
            {   // 中风
                ac_current_info.fan_speed = MEDIUM_FAN_SPEED;
                ESP_LOGI(TAG, "Received Write for ROTATION_SPEED: Medium");
            }
            else if (write->val.f > 66 && write->val.f < 100)
            {   // 高风
                ac_current_info.fan_speed = MAX_FAN_SPEED;
                ESP_LOGI(TAG, "Received Write for ROTATION_SPEED: Max");
            }
            else if (write->val.f == 0)
            {
                ac_current_info.fan_speed = OFF_FAN_SPEED;
                ESP_LOGI(TAG, "Received Write for ROTATION_SPEED: 0/OFF");
            }
            
            // if (last_fan_mode != ac_current_info.fan_speed)
            //     enable_send = true;
            // last_fan_mode = ac_current_info.fan_speed;
            // last_fan_speed = write->val.f;  // 保存为上一个风速
            *(write->status) = HAP_STATUS_SUCCESS;
        }
        else {
            *(write->status) = HAP_STATUS_RES_ABSENT;
        }

        /* If the characteristic write was successful, update it in hap core
         */
        if (*(write->status) == HAP_STATUS_SUCCESS) {
            hap_char_update_val(write->hc, &(write->val));
        } else {
            /* Else, set the return value appropriately to report error */
            ESP_LOGE(TAG, "Received Write for Air Conditioner Failed!");
            ret = HAP_FAIL;
        }
    }
    /* 在保存设定的状态后，使能发送红外指令的信号，并且记录此时的tick计数 */
    ac_send_r05d_code_flag = true;
    ac_send_tick_count = xTaskGetTickCount();   // 更新当前要发红外时的tick计数
    if (air_conditioner_send_task_handle == NULL)   // 如果没有被创建，则创建air_conditioner_send_task任务
    {
        xTaskCreate(air_conditioner_send_task, "air_conditioner_send_task", 2048, NULL, 1, &air_conditioner_send_task_handle);  
        if (air_conditioner_send_task_handle == NULL)
            ESP_LOGE(TAG, "Create air_conditioner_send_task fail!");
    }
        
    return ret;
}

static int air_conditioner_read(hap_char_t *hc, hap_status_t *status_code, void *serv_priv, void *read_priv)
{
    int ret = HAP_SUCCESS;
    int iid = hap_char_get_iid(hc);
    int aid = hap_acc_get_aid(hap_serv_get_parent(hap_char_get_parent(hc)));
    printf("Read aid = %d, iid = %d, val = %s\n", aid, iid, emulator_print_value(hc, hap_char_get_val(hc)));
    printf("hap_char_get_type_uuid(hc) : %s\n", hap_char_get_type_uuid(hc));
    hap_val_t new_val;
    /* 更新当前模式为设定模式 */
    if (!strcmp(hap_char_get_type_uuid(hc), HAP_CHAR_UUID_CURRENT_HEATER_COOLER_STATE)) 
    {
        if (ac_current_info.mode == HEAT_MODE)
        {   // 加热模式
            new_val.u = 2;
            ESP_LOGI(TAG, "Received Read for CURRENT_HEATER_COOLER_STATE: Heat");
        }
        else if (ac_current_info.mode == COOL_MODE)
        {   // 制冷模式
            new_val.u = 3;
            ESP_LOGI(TAG, "Received Read for CURRENT_HEATER_COOLER_STATE: Cool");
        }
        else if (ac_current_info.mode == AUTO_MODE)
        {   // 自动模式
            new_val.u = 1;  // 显示为Idle
            ESP_LOGI(TAG, "Received Read for CURRENT_HEATER_COOLER_STATE: Cool");
        }
        *status_code = HAP_STATUS_SUCCESS;
    }
    /* 更新当前温度为空调设定温度 */
    else if (!strcmp(hap_char_get_type_uuid(hc), HAP_CHAR_UUID_CURRENT_TEMPERATURE)) 
    {
        new_val.f = ac_current_info.temp;
        ESP_LOGI(TAG, "Received Read for CURRENT_TEMPERATURE: %d", ac_current_info.temp);
        *status_code = HAP_STATUS_SUCCESS;
    }
    /* 下面这些特征有读写权限，在write回调函数中可以被更新 */
    /* 开关状态 */
    else if (!strcmp(hap_char_get_type_uuid(hc), HAP_CHAR_UUID_ACTIVE))
    {
        *status_code = HAP_STATUS_SUCCESS;
        return HAP_SUCCESS;     // 因为这些特征不需要被更新，为了防止后面的hap_char_update_val传入的为空，直接返回
    }
    /* 目标加热冷却状态 */
    else if (!strcmp(hap_char_get_type_uuid(hc), HAP_CHAR_UUID_TARGET_HEATER_COOLER_STATE))
    {
        *status_code = HAP_STATUS_SUCCESS;
        return HAP_SUCCESS;
    }
    /* 加热温度门限 */
    else if (!strcmp(hap_char_get_type_uuid(hc), HAP_CHAR_UUID_HEATING_THRESHOLD_TEMPERATURE))
    {   // 修改为空调设定温度，而非门限
        new_val.f = ac_current_info.temp;  // 更新为空调设定温度
        ESP_LOGI(TAG, "Received Read for HEATING_THRESHOLD_TEMPERATURE: %d", ac_current_info.temp);
        *status_code = HAP_STATUS_SUCCESS;
    }
    /* 冷却温度门限 */
    else if (!strcmp(hap_char_get_type_uuid(hc), HAP_CHAR_UUID_COOLING_THRESHOLD_TEMPERATURE))
    {
        new_val.f = ac_current_info.temp;    // 更新为空调设定温度
        ESP_LOGI(TAG, "Received Read for COOLING_THRESHOLD_TEMPERATURE: %d", ac_current_info.temp);
        *status_code = HAP_STATUS_SUCCESS;
    }
    /* 名字 */
    else if (!strcmp(hap_char_get_type_uuid(hc), HAP_CHAR_UUID_NAME))
    {
        *status_code = HAP_STATUS_SUCCESS;
        return HAP_SUCCESS;
    }
    /* 风速 */
    else if (!strcmp(hap_char_get_type_uuid(hc), HAP_CHAR_UUID_ROTATION_SPEED))
    {
        *status_code = HAP_STATUS_SUCCESS;
        return HAP_SUCCESS;
    }
    else 
    {
        *status_code = HAP_STATUS_RES_ABSENT;
    }

    if (*status_code == HAP_STATUS_SUCCESS)
    {
        hap_char_update_val(hc, &new_val);
    } else {
        ret = HAP_FAIL;
    }
    
    return ret;
}

/*The main thread for handling the Air Conditioner Accessory */
static void air_conditioner_thread_entry(void *arg)
{
    hap_acc_t *accessory;
    hap_serv_t *service;

    /* Initialize the HAP core */
    hap_init(HAP_TRANSPORT_WIFI);

    /* Initialise the mandatory parameters for Accessory which will be added as
     * the mandatory services internally
     */
    hap_acc_cfg_t cfg = {
        .name = "AirConditioner_dormitory",
        .manufacturer = "DM",
        .model = "Esp32_01",
        .serial_num = "0000001",
        .fw_rev = "0.1.1",
        .hw_rev = "1.0",
        .pv = "1.1.0",
        .identify_routine = air_conditioner_identify,
        .cid = HAP_CID_AIR_CONDITIONER,
    };

    /* Create accessory object */
    accessory = hap_acc_create(&cfg);
    if (!accessory) {
        ESP_LOGE(TAG, "Failed to create accessory");
        goto air_conditioner_err;
    }

    /* Add a dummy Product Data */
    uint8_t product_data[] = {'E','S','P','3','2','H','A','P'};
    hap_acc_add_product_data(accessory, product_data, sizeof(product_data));

    /* Create the Air Conditioner Service. Include the "name" since this is a user visible service  */
    service = hap_air_conditioner_create();
    if (!service) {
        ESP_LOGE(TAG, "Failed to create air_conditioner Service");
        goto air_conditioner_err;
    }

    /* Add the optional characteristic to the Air Conditioner Service */
    int ret = hap_serv_add_char(service, hap_char_name_create("air_conditioner_DM"));
    ret |= hap_serv_add_char(service, hap_char_rotation_speed_create(100.0));    // 添加转速
    if (ret != HAP_SUCCESS) {
        ESP_LOGE(TAG, "Failed to add optional characteristics to AirConditioner");
        goto air_conditioner_err;
    }
    /* Set the write callback for the service */
    hap_serv_set_write_cb(service, air_conditioner_write);
    
    hap_serv_set_read_cb(service, air_conditioner_read);
    /* Add the Air Conditioner Service to the Accessory Object */
    hap_acc_add_serv(accessory, service);

#ifdef CONFIG_FIRMWARE_SERVICE
    /*  Required for server verification during OTA, PEM format as string  */
    static char server_cert[] = {};
    hap_fw_upgrade_config_t ota_config = {
        .server_cert_pem = server_cert,
    };
    /* Create and add the Firmware Upgrade Service, if enabled.
     * Please refer the FW Upgrade documentation under components/homekit/extras/include/hap_fw_upgrade.h
     * and the top level README for more information.
     */
    service = hap_serv_fw_upgrade_create(&ota_config);
    if (!service) {
        ESP_LOGE(TAG, "Failed to create Firmware Upgrade Service");
        goto air_conditioner_err;
    }
    hap_acc_add_serv(accessory, service);
#endif

    /* Add the Accessory to the HomeKit Database */
    hap_add_accessory(accessory);

    /* Initialize the air conditioner Bulb Hardware */
    air_conditioner_init();

    /* Register a common button for reset Wi-Fi network and reset to factory.
     */
    reset_key_init(RESET_GPIO);

    /* TODO: Do the actual hardware initialization here */

    /* For production accessories, the setup code shouldn't be programmed on to
     * the device. Instead, the setup info, derived from the setup code must
     * be used. Use the factory_nvs_gen utility to generate this data and then
     * flash it into the factory NVS partition.
     *
     * By default, the setup ID and setup info will be read from the factory_nvs
     * Flash partition and so, is not required to set here explicitly.
     *
     * However, for testing purpose, this can be overridden by using hap_set_setup_code()
     * and hap_set_setup_id() APIs, as has been done here.
     */
#ifdef CONFIG_EXAMPLE_USE_HARDCODED_SETUP_CODE
    /* Unique Setup code of the format xxx-xx-xxx. Default: 111-22-333 */
    hap_set_setup_code(CONFIG_EXAMPLE_SETUP_CODE);
    /* Unique four character Setup Id. Default: ES32 */
    hap_set_setup_id(CONFIG_EXAMPLE_SETUP_ID);
#ifdef CONFIG_APP_WIFI_USE_WAC_PROVISIONING
    app_hap_setup_payload(CONFIG_EXAMPLE_SETUP_CODE, CONFIG_EXAMPLE_SETUP_ID, true, cfg.cid);
#else
    app_hap_setup_payload(CONFIG_EXAMPLE_SETUP_CODE, CONFIG_EXAMPLE_SETUP_ID, false, cfg.cid);
#endif
#endif

    /* Enable Hardware MFi authentication (applicable only for MFi variant of SDK) */
    hap_enable_mfi_auth(HAP_MFI_AUTH_HW);

    /**
     * Configure dynamic frequency scaling:
     * maximum and minimum frequencies are set in sdkconfig,
     * automatic light sleep is enabled if tickless idle support is enabled. 
     * 
     */
#if CONFIG_PM_ENABLE
#if CONFIG_IDF_TARGET_ESP32
    esp_pm_config_esp32_t pm_config = {
        .max_freq_mhz = CONFIG_APP_MAX_CPU_FREQ_MHZ,
        .min_freq_mhz = CONFIG_APP_MIN_CPU_FREQ_MHZ,
#if CONFIG_FREERTOS_USE_TICKLESS_IDLE
        .light_sleep_enable = true
#endif
    };
    ESP_ERROR_CHECK(esp_pm_configure(&pm_config));
#endif
#endif

    ESP_ERROR_CHECK(esp_pm_lock_create(ESP_PM_NO_LIGHT_SLEEP, 0, "rmt_send_task", &rmt_send_task_pm_lock));     // 创建锁
    /* Initialize Wi-Fi */
    app_wifi_init();

    /* After all the initializations are done, start the HAP core */
    hap_start();
    /* Start Wi-Fi */
    app_wifi_start(portMAX_DELAY);

    /* The task ends here. The read/write callbacks will be invoked by the HAP Framework */
    vTaskDelete(NULL);

air_conditioner_err:
    hap_acc_delete(accessory);
    vTaskDelete(NULL);
}

/** 在write回调函数更新红外指令后的一段时间内，如果没有新的更新，才发送，否则知道没有新的更新为止再发送
 * 因为在家庭App进行模式切换时，会被调用两次write回调函数，为了防止发重复指令
 * 也防止在改变风速这一特征时，造成发送频率太高
 */
static void air_conditioner_send_task(void *arg)
{
    TickType_t nowTickCount = 0;
    
    while (1)
    {
        if (ac_send_r05d_code_flag == true)
        {
            nowTickCount = xTaskGetTickCount();
            if ((TickType_t)(nowTickCount - ac_send_tick_count) > pdMS_TO_TICKS(1500))
            {
                esp_pm_lock_acquire(rmt_send_task_pm_lock);  // 获取锁
                ac_send_r05d_code(ac_current_info);
                ac_send_r05d_code_flag = false;
                esp_pm_lock_release(rmt_send_task_pm_lock); // 释放锁
                air_conditioner_send_task_handle = NULL;    // 赋值为NULL 也就是删除自己
                vTaskDelete(air_conditioner_send_task_handle);      // 发送一次后删除任务

            }
        }
        vTaskDelay(pdMS_TO_TICKS(100));
    }
    
}
#ifdef CONFIG_PM_PROFILING
/**
 * 用来打印相关pm的信息
 */
static void pm_track_task(void *arg)
{
    while (1)
    {
        esp_pm_dump_locks(stdout);
        vTaskDelay(pdMS_TO_TICKS(5000));
    }
    
    
}
#endif
void app_main()
{
    xTaskCreate(air_conditioner_thread_entry, AIRCONDITIONER_TASK_NAME, AIRCONDITIONER_TASK_STACKSIZE,
            NULL, AIRCONDITIONER_TASK_PRIORITY, NULL);
#ifdef CONFIG_PM_PROFILING
    xTaskCreate(pm_track_task, "pm_track_task", 2048, NULL, 0, NULL);
#endif
}

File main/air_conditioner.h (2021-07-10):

#ifndef _AIR_CONDITIONER_H_
#define _AIR_CONDITIONER_H_


#include "hap.h"

#define RMT_TX_GPIO     GPIO_NUM_18
/* 空调设定模式 */
typedef enum {
    AUTO_MODE = 0,
    COOL_MODE,
    HEAT_MODE
}AC_MODE;

/* 空调设定的风速 */
typedef enum {
    AUTO_FAN_SPEED = 0,
    MIN_FAN_SPEED,
    MEDIUM_FAN_SPEED,
    MAX_FAN_SPEED,
    FIXED_FAN_SPEED,
    OFF_FAN_SPEED
}AC_FAN_SPEED;

/* R05D码格式 */
typedef struct {
    uint8_t A;
    uint8_t A_;     // A的按位取反
    uint8_t B;
    uint8_t B_;
    uint8_t C;
    uint8_t C_;
}AC_R05D_PAYLOAD_CODE;

/* 空调指令信息 */
typedef struct {
    bool on;        // 记录空调开关状态
    AC_MODE mode;   // 记录当前空调设定的模式
    uint8_t temp;   // 记录当前空调设定的温度
    AC_FAN_SPEED fan_speed;   // 记录当前空调设定的风速
}AC_INFO;
/* 下面部分参考 https://github.com/crankyoldgit/IRremoteESP8266/blob/master/src/ir_Coolix.h */
/* 风速代码 */
#define kCoolixFanMin  (0b100)
#define kCoolixFanMed  (0b010)
#define kCoolixFanMax  (0b001)
#define kCoolixFanAuto (0b101)
#define kCoolixFanAuto0 (0b000)     // 固定风
/* 模式代码 只选用了四种模式 */
#define kCoolixCool (0b00)
#define kCoolixDry  (0b01)
#define kCoolixAuto (0b10)
#define kCoolixHeat (0b11)

/* 温度代码 */
#define kCoolixTempMin  (17)  // Celsius
#define kCoolixTempMax  (30)  // Celsius
#define kCoolixTempRange (kCoolixTempMax - kCoolixTempMin + 1)


/**
 * @brief initialize the air conditioner 
 *
 * @param none
 *
 * @return none
 */
void air_conditioner_init(void);



/**
 * @brief 创建空调服务
 * 
 * @return hap_serv_t* HAP Service handle
 */
hap_serv_t *hap_air_conditioner_create(void);

/**
 * @brief 根据风速、温度、模式等(todo)通过红外二极管发送r05d指令
 * 
 * @param ac_info 空调设置信息
 * 
 * @return void
 */
void ac_send_r05d_code(AC_INFO ac_info);

/**
 * @brief 清除申请的内存空间以及失能红外配置
 * 
 */
void air_conditioner_deinit(void);



#endif /* _AIR_CONDITIONER_H_ */

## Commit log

2021-07-10 初次提交
    [LiBattery-ChargeAndDischarge.PcbDoc, LiBattery-ChargeAndDischarge.PrjPcb, LiBattery-ChargeAndDischarge.SchDoc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]
2021-07-10 注释了HomeKit回调中一行DEBUG输出
2021-07-10 添加了原理图PDF版本
2021-07-13 更新readme
2021-07-15 更新了原理图PCB
    [ESP32_AC_Controller.PcbDoc, ESP32_AC_Controller.PrjPcb, ESP32_AC_Controller.SchDoc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]
2021-07-16 更新了一行显示错误
2021-09-19 修改了根目录下CMakeLists.txt中在使用系统环境变量HOMEKIT_PATH时导致/examples/common无法找到的问题
2021-09-20 参考power_save例程添加了自动light-sleep模式，需要在HOMEKIT_PATH/example/common/app_wifi/aoo_wifi.c中app_wifi_start中添加esp_wifi_set_ps(DEFAULT_PS_MODE); 并且修改了延时发送红外编码的任务，从刚刚启动创建变为发送时创建任务。
2021-09-20 删除.vscode文件夹和sdkconfig文件
2021-09-25 在发送红外信号时，添加电源管理锁防止进入light-sleep模式以免无法发送红外信号；启用rmt_config_t中的flags。
2021-10-04 移除sdkconfig
2021-10-04 添加大概的电流测量
2021-10-04 修改readme语法错误- -
2021-10-09 把esp_pm_lock_create的第二个参数改为0。经过咨询目前这个参数是为以后更多 esp_pm_lock_type_t准备的。
